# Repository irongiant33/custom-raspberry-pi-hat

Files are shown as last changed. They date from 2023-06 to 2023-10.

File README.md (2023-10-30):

# Raspberry Pi Hat

## Purpose

Create a hardware interface for the Raspberry Pi to enable toggling of 5 LEDs of different colors, some DC fans, and a 12V solenoid. 

## Demo

https://www.youtube.com/watch?v=JTKpwDRQpkI

## Board Layout

board layout

## Design Decisions

### Using subprocess to drive Raspberry Pi GPIO outputs LOW

I noticed some strange behavior when running an older version of `gpio_driver.py` when I did not have the `subprocess` module imported. When I would `CTRL+C` exit from the program, all of the GPIO outputs would drive high - resulting in charging the capacitor for the solenoid & driving all of the LED outputs high. To me, this was undesired behavior because I didn't want the bright LEDs to be on unless the "proposal program" was actively running. 

The best reasoning for why this happened was found on the Raspberry Pi Stack Exchange (https://raspberrypi.stackexchange.com/questions/121081/leds-do-not-turn-off-after-the-raspberry-pi-powers-down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,%28set%20all%20pins%20to%20output%20and%20drive%20low%29.) where they reasoned that the operating system does this by default - this seems strange to me because the Pi could potentially have a short circuit and burn out the pins if it leaves them high.

Anyway, my solution to this was to use `subprocess` and the `raspi-gpio` script as suggested in the thread to force the outputs low. However, this results in a GPIO warning the next time `gpio_driver.py` is launched. To get around this, I just ignored the GPIO warnings.

### Push-button solenoid trigger and the one second trigger time

The two circled regions of the schematic show the RC timing circuit that keeps the pulse active. I chose to go for a time constant of 1s to enable the triggered pulse from either the Raspberry Pi or the manual switch two drive the output of the solenoid high. I decided to do this mainly for safety, but the one second was arbitrary. I observed that if the solenoid was kept in an active state for a prolonged period of time, it would begin to heat up (as well as Q11 in the schematic). To limit the dissipated power between 12V and ground, I decided to implement logic to allow for the solenoid to only trigger for 1 second at a time.

The drawback of this is that you must wait for C1 and C2 to charge back up before triggering the solenoid again. Theoretically, this should be at most one second as well, but I've observed that it is better to give it ~3 seconds to fully charge. 

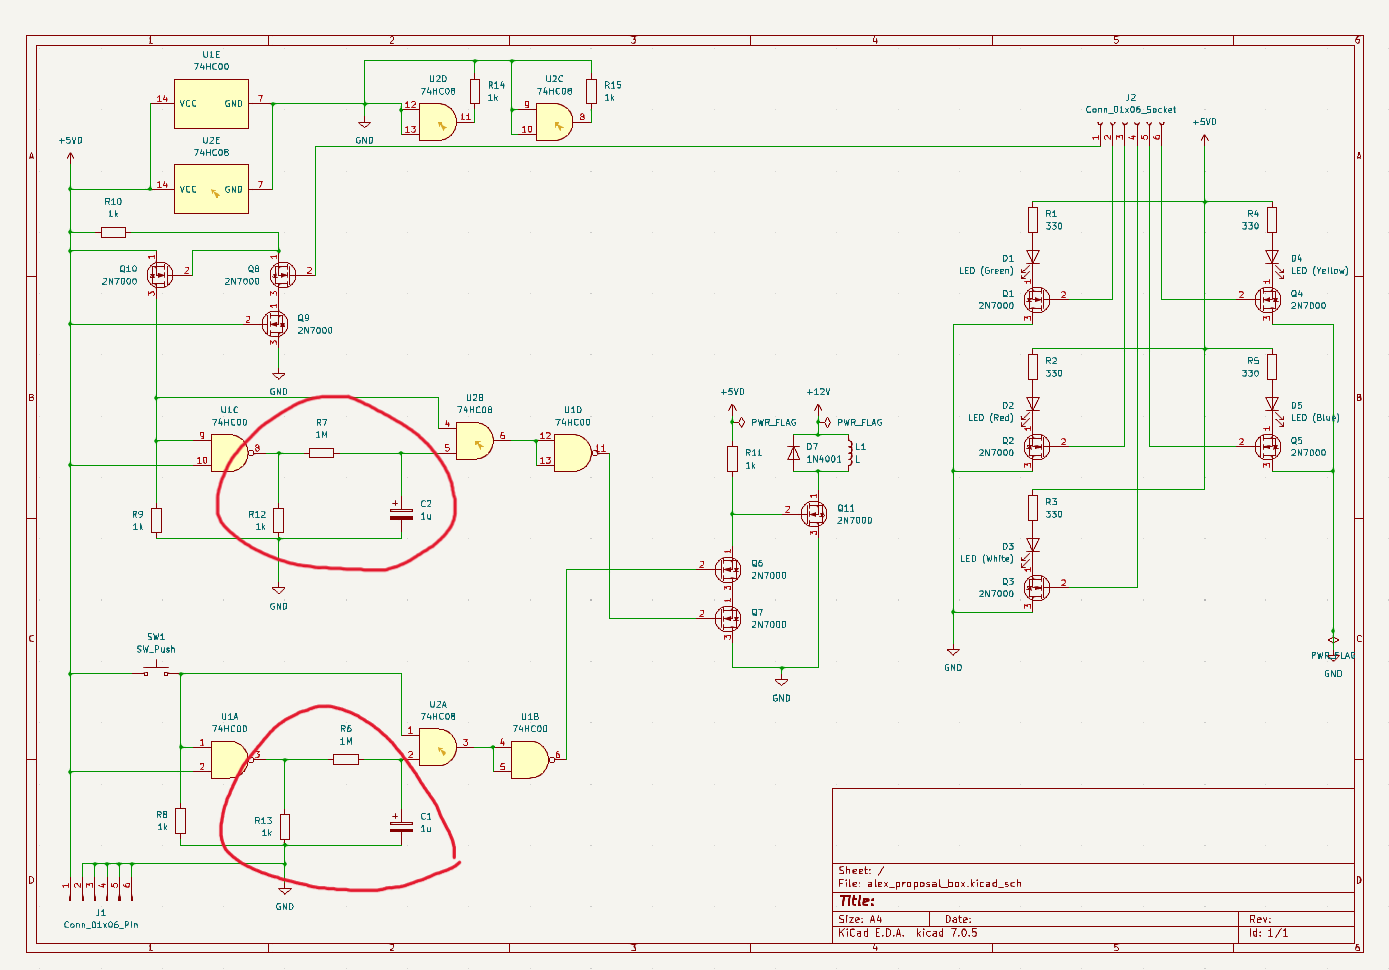
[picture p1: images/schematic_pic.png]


## PCB Printing

Check out the "pcbway-09oct23" tag to see the updates I made to the schematic and the PCB in order to make it printable. I ended up going with PCBWay to print everything, I exported the KiCad PCB file to Gerber, zipped it up, and uploaded it to PCBWay for the print. Fingers crossed everything comes out okay! 

Here is how I phrased my previous "future work""

> This would be a fun opportunity to learn more about KiCad. They have a good basic tutorial here (https://docs.kicad.org/7.0/en/getting_started_in_kicad/getting_started_in_kicad.html) which was helpful to start playing with the PCB. Soldering the prototype board was a huge PITA and I was worried that I was going to mess something up. 
>
> One area I'd have to fix with the current KiCad files that are in this folder is the footprint for some of the components are off. I was just curious what the board layout would look like, but I would have to get the footprint for the resistors, capacitors, and pin headers to match up with what I have. It would be even better if I could match the Raspberry Pi footprint to effectively create a Raspberry Pi hat. 

I completely forgot about that old "getting started" guide, but thankfully remembered most everything I needed to in order to get things to work. With the help of my digital calipers, I updated the footprints of all of the devices in my schematic to match that which I had on hand. I also heavily leaned on Raspberry Pi's schematics and mechanical drawings (https://www.raspberrypi.com/documentation/computers/raspberry-pi.html#schematics-and-mechanical-drawings) for help in making it compatible for a Pi hat. I wanted to have room for the Boost converter that I had for amazon for everything to be really compact, and this made it a challenge to fit everything together - but it fit! That constraint definitely made the via routing more interesting, but I got it to work.

I ended up editing the width of the via for the power line (anything associated with 12V) to mimic the width of 22AWG cable - however, as I've noted on the new future work, it would have been better to make an electrical simulation to know exactly what I needed here. 

## Future Work

### KiCad improvements

- Ground plane printing
- Matching the 3D rendering model to what I have in real life
    - Making my own footprints and renderings
- leveraging community templates
- Better electrical simulation to better approximate track widths

### Implement the Cmd library for gpio_driver.py

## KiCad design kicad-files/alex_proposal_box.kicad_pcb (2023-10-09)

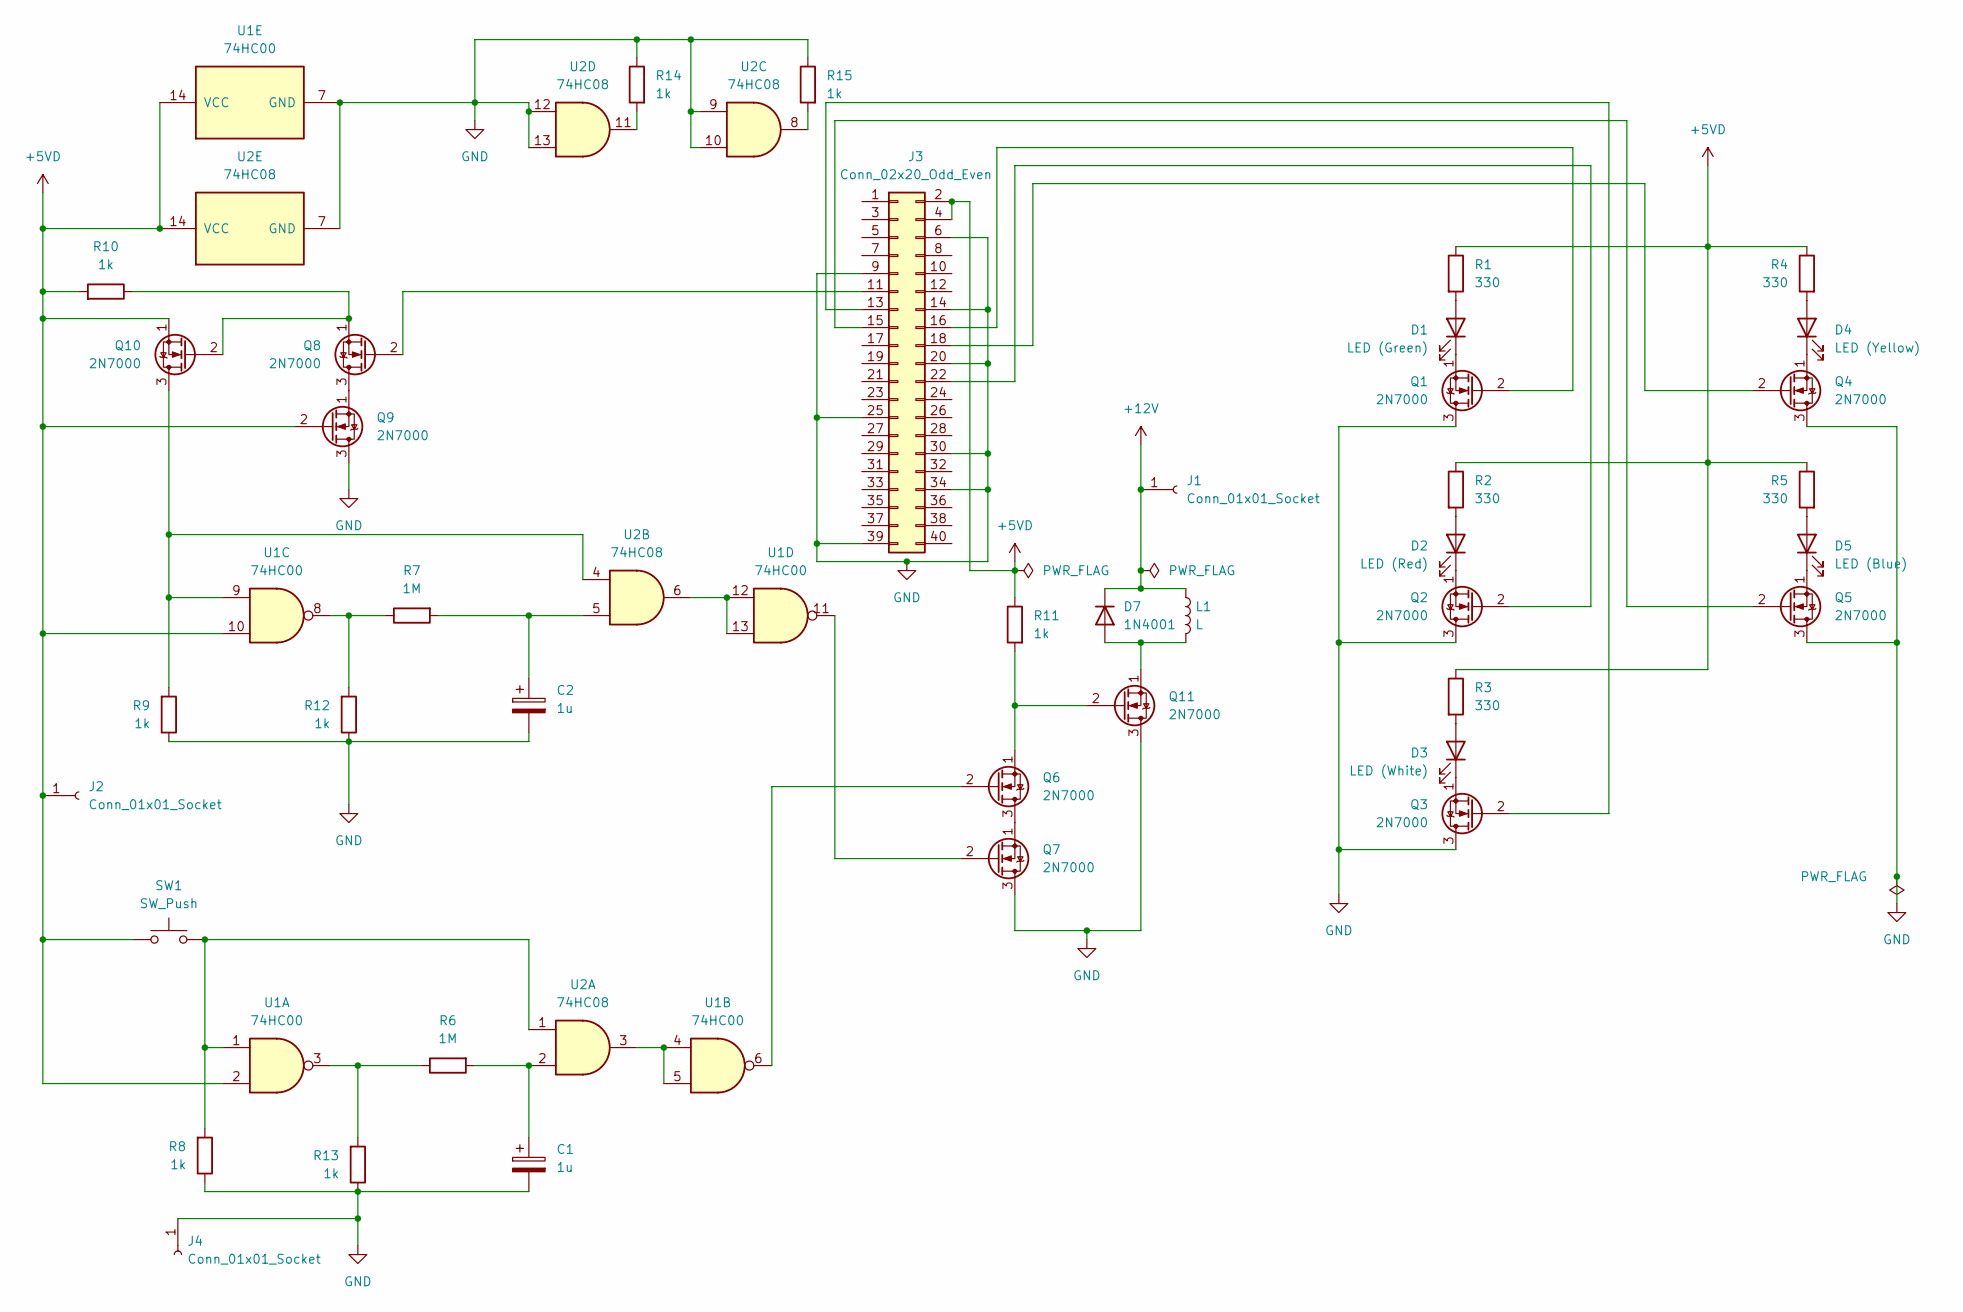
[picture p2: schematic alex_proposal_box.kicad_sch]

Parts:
C1, C2: 1u; CP_Radial_D5.0mm_P2.50mm
D1: LED (Green); D_DO-15_P2.54mm_Vertical_AnodeUp
D2: LED (Red); D_DO-15_P2.54mm_Vertical_AnodeUp
D3: LED (White); D_DO-15_P2.54mm_Vertical_AnodeUp
D4: LED (Yellow); D_DO-15_P2.54mm_Vertical_AnodeUp
D5: LED (Blue); D_DO-15_P2.54mm_Vertical_AnodeUp
D7: 1N4001; D_DO-41_SOD81_P10.16mm_Horizontal
J1, J2, J4: Conn_01x01_Socket; PinSocket_1x01_P2.00mm_Vertical
J3: Conn_02x20_Odd_Even; PinHeader_2x20_P2.54mm_Vertical
L1: L; L_Axial_L5.0mm_D3.6mm_P10.00mm_Horizontal_Murata_BL01RN1A2A2
Q1, Q2, Q3, Q4, Q5, Q6, Q7, Q8, Q9, Q10, Q11: 2N7000; TO-92_Inline
R1, R2, R3, R4, R5: 330; R_Axial_DIN0411_L9.9mm_D3.6mm_P12.70mm_Horizontal
R6, R7: 1M; R_Axial_DIN0411_L9.9mm_D3.6mm_P12.70mm_Horizontal
R8, R9, R10, R11, R12, R13, R14, R15: 1k; R_Axial_DIN0411_L9.9mm_D3.6mm_P12.70mm_Horizontal
SW1: SW_Push; SW_PUSH-6.5mm
U1: 74HC00; DIP-14_W7.62mm_Socket_LongPads
U2: 74HC08; DIP-14_W7.62mm_Socket_LongPads

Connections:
+5VD: J2.1, J3.2, J3.4, Q9.2 (G), Q10.1 (S), R1.1, R2.1, R3.1, R4.1, R5.1, R10.2, R11.1, SW1.1, U1.2, U1.10, U1.14 (VCC), U2.14 (VCC)
+12V: D7.1 (K), J1.1, L1.1
GND: C1.2, C2.2, J3.6, J3.9, J3.14, J3.20, J3.25, J3.30, J3.34, J3.39, J4.1, Q1.3 (D), Q2.3 (D), Q3.3 (D), Q4.3 (D), Q5.3 (D), Q7.3 (D), Q9.3 (D), Q11.3 (D), R8.1, R9.1, R12.1, R13.1, R14.1, R15.1, U1.7 (GND), U2.7 (GND), U2.9, U2.10, U2.12, U2.13
unnamed: C1.1, R6.2, U2.2
unnamed: C2.1, R7.2, U2.5
unnamed: D1.2 (A), R1.2
unnamed: D1.1 (K), Q1.1 (S)
unnamed: D2.2 (A), R2.2
unnamed: D2.1 (K), Q2.1 (S)
unnamed: D3.2 (A), R3.2
unnamed: D3.1 (K), Q3.1 (S)
unnamed: D4.2 (A), R4.2
unnamed: D4.1 (K), Q4.1 (S)
unnamed: D5.2 (A), R5.2
unnamed: D5.1 (K), Q5.1 (S)
unnamed: D7.2 (A), L1.2, Q11.1 (S)
unnamed: J3.11, Q8.2 (G)
unnamed: J3.13, Q3.2 (G)
unnamed: J3.15, Q5.2 (G)
unnamed: J3.16, Q1.2 (G)
unnamed: J3.18, Q4.2 (G)
unnamed: J3.22, Q2.2 (G)
unnamed: Q6.3 (D), Q7.1 (S)
unnamed: Q6.2 (G), U1.6
unnamed: Q7.2 (G), U1.11
unnamed: Q8.3 (D), Q9.1 (S)
unnamed: Q10.3 (D), R9.2, U1.9, U2.4
unnamed: Q8.1 (S), Q10.2 (G), R10.1
unnamed: Q6.1 (S), Q11.2 (G), R11.2
unnamed: R8.2, SW1.2, U1.1, U2.1
unnamed: R7.1, R12.2, U1.8
unnamed: R6.1, R13.2, U1.3
unnamed: R14.2, U2.11
unnamed: R15.2, U2.8
unnamed: U1.4, U1.5, U2.3
unnamed: U1.12, U1.13, U2.6

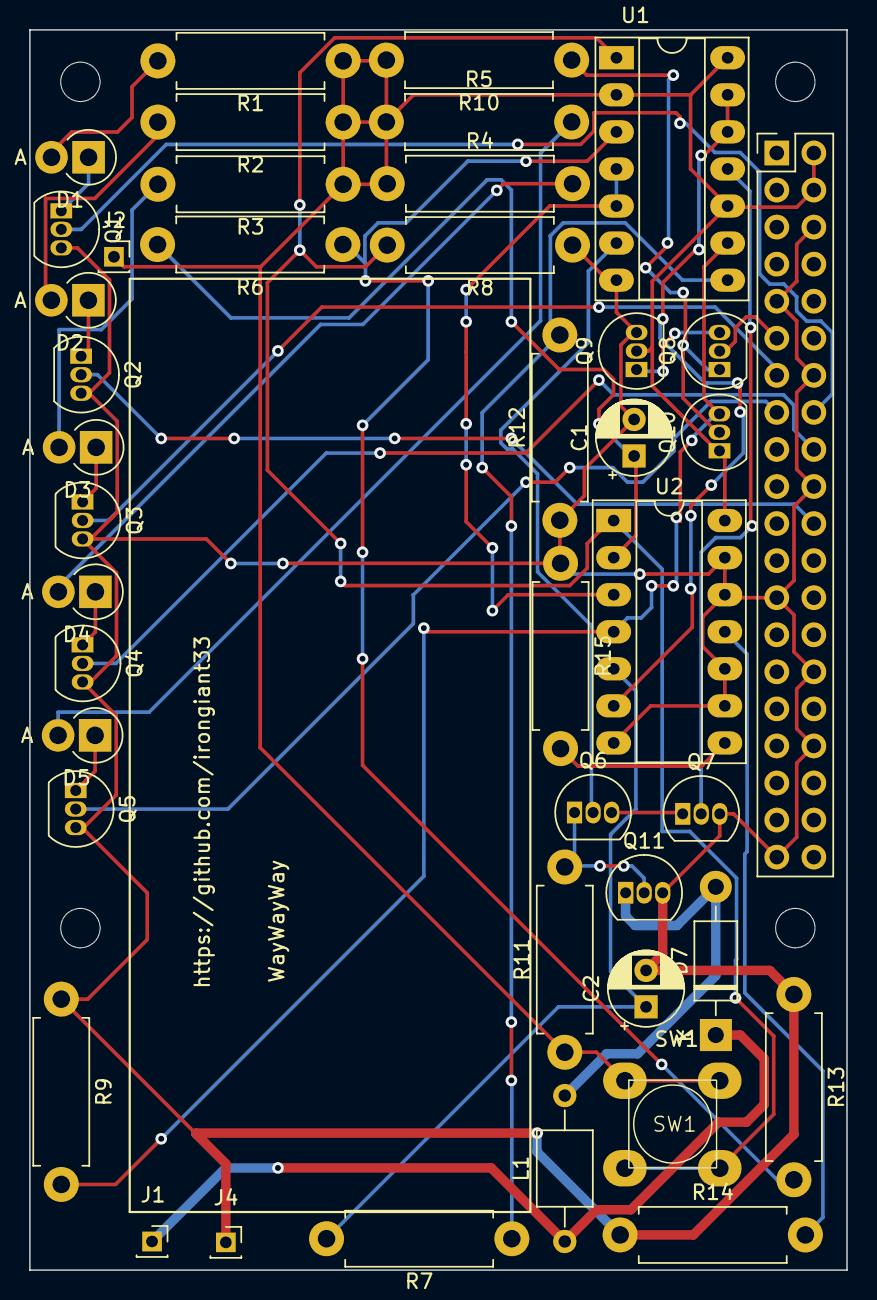
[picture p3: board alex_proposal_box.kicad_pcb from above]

Board: 2 copper layers, 56.0 x 85.0 mm, 42 parts (0 on the bottom side), 36 nets.

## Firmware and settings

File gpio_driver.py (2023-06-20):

import RPi.GPIO as GPIO
from time import sleep
import subprocess

CAPACITOR_CHARGE_TIME = 3 # in seconds, should be sufficient to charge the capacitor - you could probably get away with as few as 1s

"""
@brief function to trigger the solenoid. Requires charging the capacitor prior to activation
@param pin (int): BCM pin that controls the solenoid
@param value (int): current output value on the pin
@param name (str): name of the output device
@return new_value (int): the same input value
"""
def solenoid_driver(pin, value, name):
    new_value = value
    GPIO.output(pin, 1)
    print("sleeping 3s to charge the capacitor")
    sleep(CAPACITOR_CHARGE_TIME)
    input(f"press any key to trigger the {name}!")
    GPIO.output(pin, 0)
    return new_value

"""
@brief function to toggle a led.
@param pin (int): BCM pin that controls the led
@param value (int): current output value on the pin
@param name (str): name of the output device
@return new_value (int): the new state of the output pin
"""
def led_driver(pin, value, name):
    led = char
    new_value = (value + 1) % 2
    GPIO.output(pin, new_value)
    print(f"setting {name} from {value} to {new_value}")
    return new_value

# gpio.board for Raspberry Pi 4 Model B is 11, GPIO port for Broadcom SOC (BCM) is 17
OUTPUT_BCM_PINS   = {  
                  "S": [17, 0, "Solenoid", solenoid_driver],
                  "G": [23, 0, "Green", led_driver],
                  "B": [22, 0, "Blue", led_driver],
                  "R": [25, 0, "Red", led_driver],
                  "Y": [24, 0, "Yellow", led_driver],
                  "W": [27, 0, "White", led_driver]
                 }
PIN_INDEX      = 0 # index of the list to find LED_BCM_PINS pin assignment
VALUE_INDEX    = 1 # index of the list to find LED_BCM_PINS output value
NAME_INDEX     = 2 # index of the name of the led
FUNC_INDEX     = 3 # index of the driver function for that output

"""
@brief function to drive all GPIO outputs to 0
@return None
"""
def zeroize_gpio():
    for _, state in OUTPUT_BCM_PINS.items():
        GPIO.output(state[PIN_INDEX], 0)

if __name__ == "__main__":
    # setup GPIO
    GPIO.setwarnings(False) # see README for why this is set to False
    GPIO.setmode(GPIO.BCM)
    for _, state in OUTPUT_BCM_PINS.items():
        GPIO.setup(state[PIN_INDEX], GPIO.OUT)
    zeroize_gpio()

    # enter endless user input loop
    try:
        while True:
            user_input = input("press S key to charge the capacitor, type R, G, B, Y, or W to toggle that LED\n> ")
            unique_user_input = list(set(user_input.upper()))
            for char in unique_user_input:
                if (char in OUTPUT_BCM_PINS.keys()):
                    OUTPUT_BCM_PINS[char][VALUE_INDEX] = OUTPUT_BCM_PINS[char][FUNC_INDEX](OUTPUT_BCM_PINS[char][PIN_INDEX],
                                                                                           OUTPUT_BCM_PINS[char][VALUE_INDEX],
                                                                                           OUTPUT_BCM_PINS[char][NAME_INDEX])
                else:
                    print(f"input {char} not recognized")
    except KeyboardInterrupt:
        print("\nKeyboard interrupt detected, exiting...")

    # drive all pins to low. See README for explanation of subprocess use.
    zeroize_gpio()
    GPIO.cleanup()
    for _, state in OUTPUT_BCM_PINS.items():
        subprocess.run(['raspi-gpio', 'set', f'{state[PIN_INDEX]}', 'op', 'dl'])

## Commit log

2023-06-19 adding kicad files
    [alex_proposal_box.kicad_pcb, alex_proposal_box.kicad_sch]
2023-06-20 updating pcb layout
    [alex_proposal_box.kicad_pcb, alex_proposal_box.kicad_sch]
2023-06-20 editing the gpio driver to make it slightly more Pythonic
2023-06-21 adding video and image of the circuit
2023-06-21 adding board layout and link to video demo
2023-10-09 made the schematic printable on a PCB
    [alex_proposal_box.kicad_pcb, alex_proposal_box.kicad_sch]
2023-10-09 editing future work section to reflect new PCB improvements
